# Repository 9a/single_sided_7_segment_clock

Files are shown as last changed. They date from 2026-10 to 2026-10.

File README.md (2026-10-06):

# Single Sided 7 segment clock PCB (optimized for use with ESP D1 Mini/ESP-home)
A pcb design for a 7 segment clock for single sided milled pcbs. Designed with KiCad 10. 

BOM (alternatives are also OK):
- 2x SN74HC595DR 
- 29x 150080RS75000
- 8x 10 Ohm 0805 (or 0603)

See schematic/placement picture for assembly (diode orientation!). The through holes other than for the 5 pin connector need to be connected via jumper wires.

It is designed to be connected to a USB-C ESP8266 D1-mini with a one to one connection via jumper wires to the pins 5V GND D4 D3 D2. Since the pins expose the control pins of the shift registers any microcontroller can be adapted.

For use with ESP home in Homeassistant:
The provided esp_yaml.txt can be copied when creating the device, the cnc_display.h needs to be copied into the esphome directory.

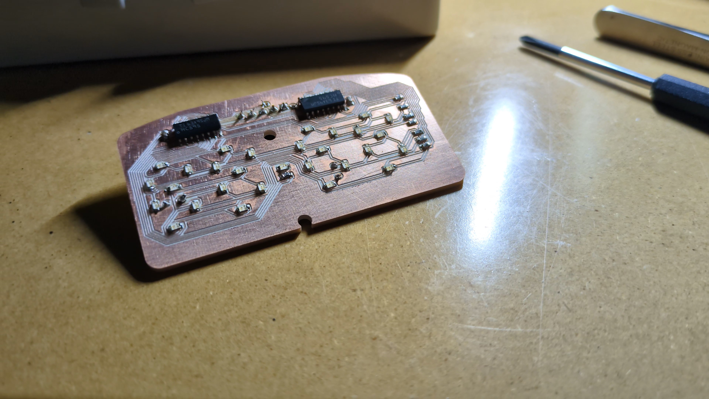
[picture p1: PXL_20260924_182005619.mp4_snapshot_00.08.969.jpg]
PCB


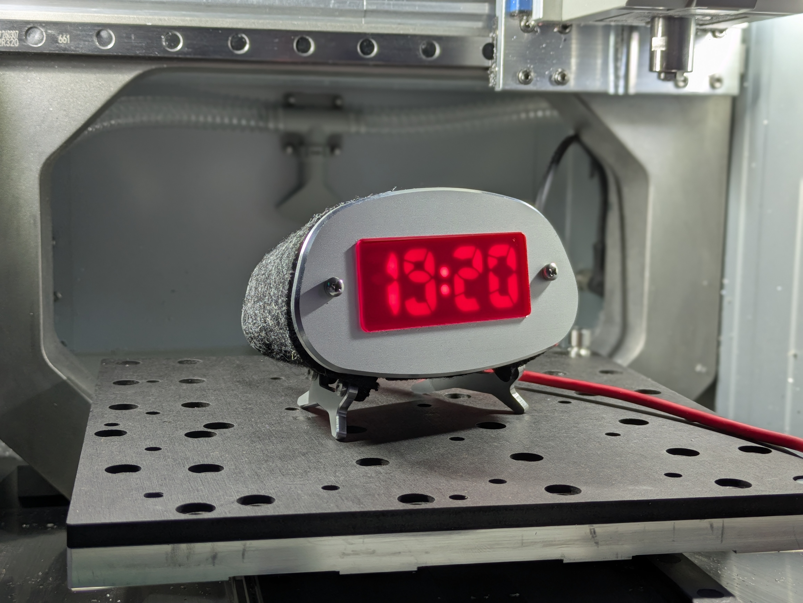
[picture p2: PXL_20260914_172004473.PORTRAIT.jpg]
finished_clock


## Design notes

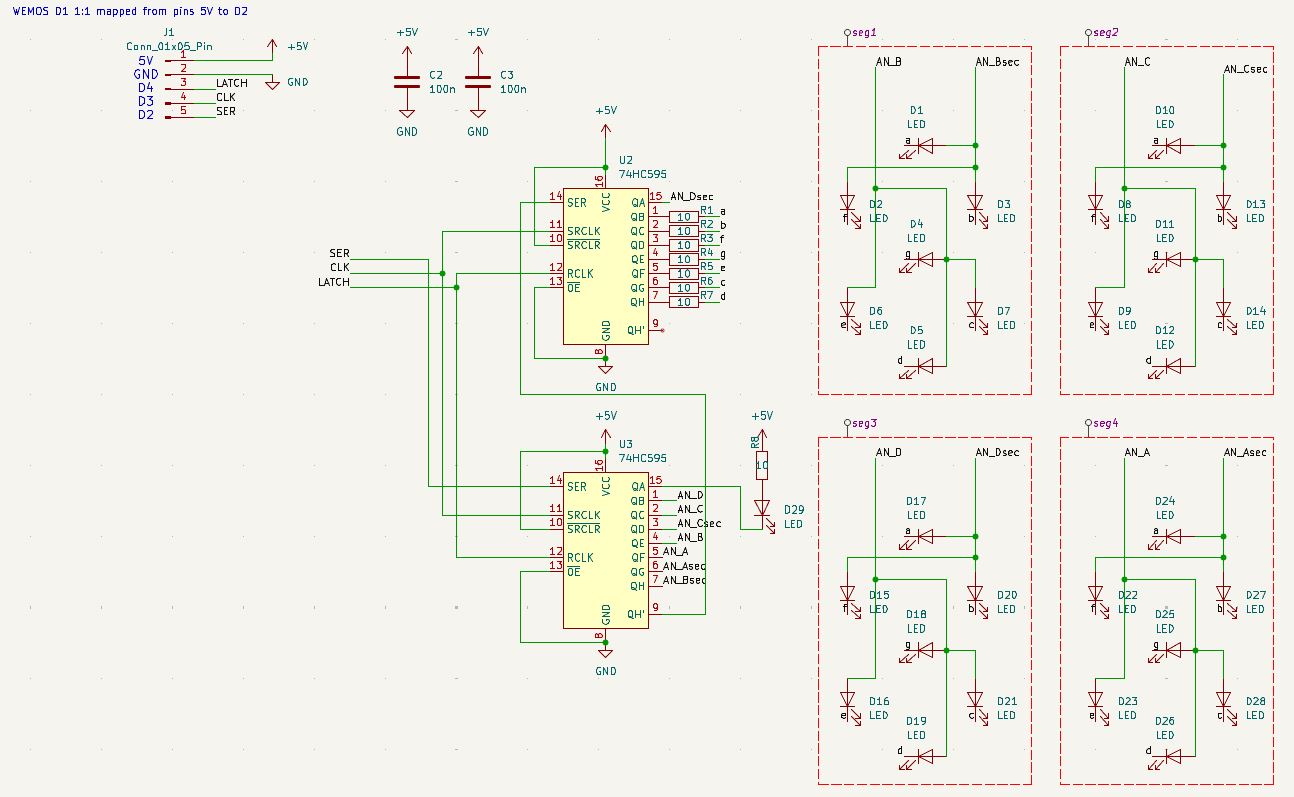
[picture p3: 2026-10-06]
esp_clock_schematic.JPG

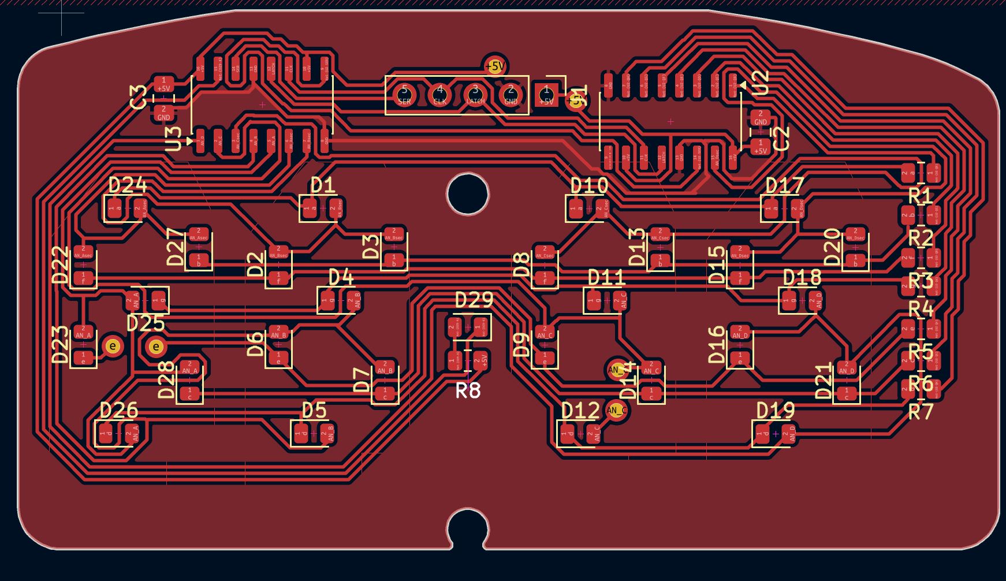
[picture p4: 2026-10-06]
placement.JPG

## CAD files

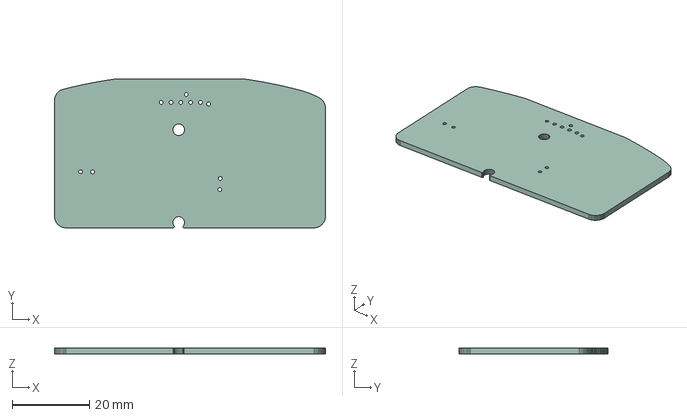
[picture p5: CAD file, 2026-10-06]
clock_pcb.step
70.1 x 38.5 x 1.51 mm

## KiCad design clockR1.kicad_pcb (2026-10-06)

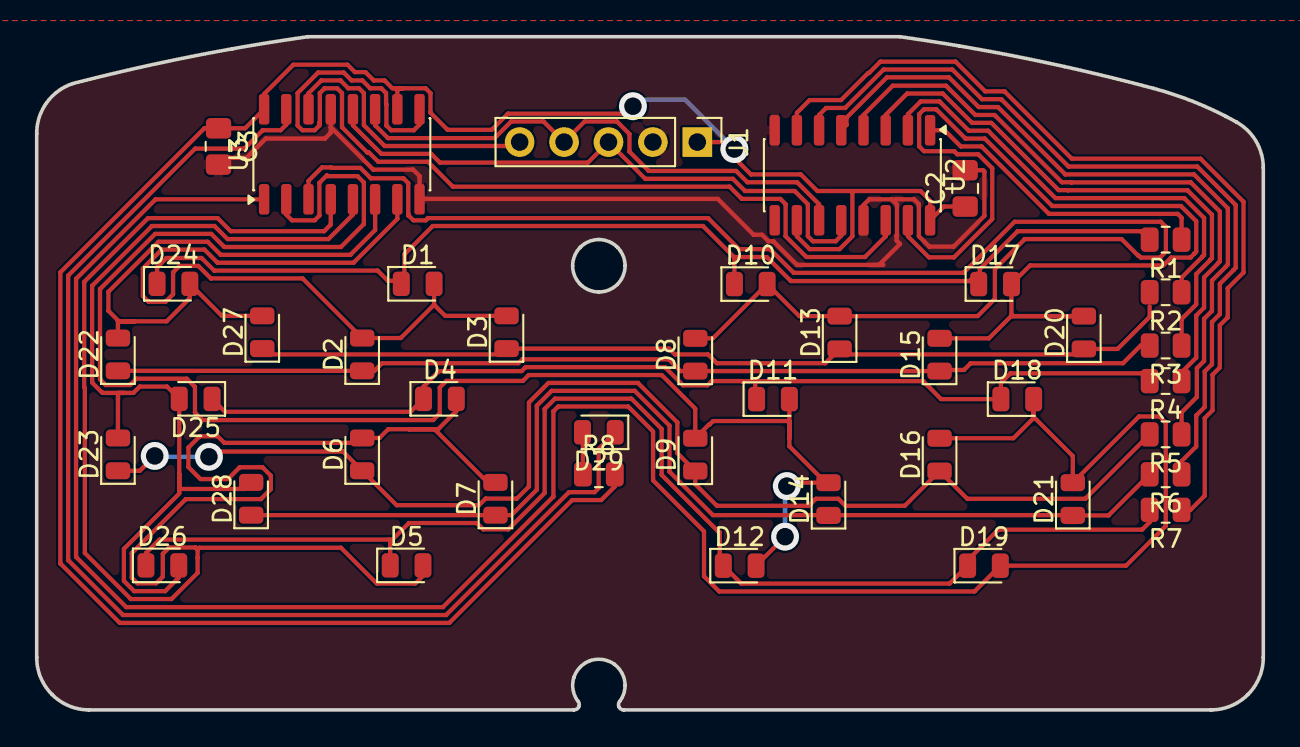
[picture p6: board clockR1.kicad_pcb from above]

Board: 2 copper layers, 70.1 x 38.5 mm, 42 parts (0 on the bottom side), 30 nets.

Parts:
C2, C3: C; C_0805_2012Metric_Pad1.18x1.45mm_HandSolder
D1, D2, D3, D4, D5, D6, D7, D8, D9, D10, D11, D12, D13, D14, D15, D16, D17, D18, D19, D20, D21, D22, D23, D24, D25, D26, D27, D28, D29: LED; LED_0805_2012Metric
J1: Conn_01x05_Pin; PinHeader_1x05_P2.54mm_Vertical
R1, R2, R3, R4, R5, R6, R7, R8: 100; R_0805_2012Metric
U2, U3: 74HC595; SO-16_3.9x9.9mm_P1.27mm

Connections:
+5V: C2.1, C3.1, J1.1, R8.2, U2.10 (~SRCLR), U2.16 (VCC), U3.10 (~SRCLR), U3.16 (VCC)
/AN_A: D23.2 (A), D25.2 (A), D26.2 (A), D28.2 (A), U3.5 (QF)
/AN_Asec: D22.2 (A), D24.2 (A), D27.2 (A), U3.6 (QG)
/AN_B: D4.2 (A), D5.2 (A), D6.2 (A), D7.2 (A), U3.4 (QE)
/AN_Bsec: D1.2 (A), D2.2 (A), D3.2 (A), U3.7 (QH)
/AN_C: D9.2 (A), D11.2 (A), D12.2 (A), D14.2 (A), U3.2 (QC)
/AN_Csec: D8.2 (A), D10.2 (A), D13.2 (A), U3.3 (QD)
/AN_D: D16.2 (A), D18.2 (A), D19.2 (A), D21.2 (A), U3.1 (QB)
/AN_Dsec: D15.2 (A), D17.2 (A), D20.2 (A), U2.15 (QA)
/CLK: J1.4, U2.11 (SRCLK), U3.11 (SRCLK)
/LATCH: J1.3, U2.12 (RCLK), U3.12 (RCLK)
/SER: J1.5, U3.14 (SER)
/a: D1.1 (K), D10.1 (K), D17.1 (K), D24.1 (K), R1.2
/b: D3.1 (K), D13.1 (K), D20.1 (K), D27.1 (K), R2.2
/c: D7.1 (K), D14.1 (K), D21.1 (K), D28.1 (K), R6.2
/d: D5.1 (K), D12.1 (K), D19.1 (K), D26.1 (K), R7.2
/e: D6.1 (K), D9.1 (K), D16.1 (K), D23.1 (K), R5.2
/f: D2.1 (K), D8.1 (K), D15.1 (K), D22.1 (K), R3.2
/g: D4.1 (K), D11.1 (K), D18.1 (K), D25.1 (K), R4.2
GND: C2.2, C3.2, J1.2, U2.8 (GND), U2.13 (~OE), U3.8 (GND), U3.13 (~OE)
unnamed: D29.2 (A), R8.1
unnamed: D29.1 (K), U3.15 (QA)
unnamed: R1.1, U2.1 (QB)
unnamed: R2.1, U2.2 (QC)
unnamed: R3.1, U2.3 (QD)
unnamed: R4.1, U2.4 (QE)
unnamed: R5.1, U2.5 (QF)
unnamed: R6.1, U2.6 (QG)
unnamed: R7.1, U2.7 (QH)
unnamed: U2.14 (SER), U3.9 (QH')

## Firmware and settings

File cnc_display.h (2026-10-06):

/*
*  This program originally was programmed for Arduino and
*  was vibe-ported to ESP home via ChatGPT.
*
*  All digits have common segment lines and are multiplexed
*  Pin assignment was optimized for single sided PCB routing
*  Check the KiCad dchematic for details.
*/

#pragma once

#include <Arduino.h>
#include <stdint.h>

// ============================================================
// ORIGINAL WIRING
//
// D4 / GPIO2 = LATCH
// D3 / GPIO0 = CLOCK
// D2 / GPIO4 = DATA
//
// No hardware SPI.
// ============================================================

#define CNC_LATCH  2
#define CNC_CLOCK  0
#define CNC_DATA   4


// ============================================================
// DISPLAY TIMING
//
// 1000 us per digit (4ms for all of the display)
//
// ============================================================

#define CNC_DIGIT_PERIOD_US 1000


// ============================================================
// ESP8266 timer1
//
// TIM_DIV16:
//
// 80 MHz / 16 = 5 MHz
//
// 1 timer tick = 200 ns
//
// ============================================================

#define CNC_TIMER_TICKS_PER_US 5


// ============================================================
// Blanking time
//
// Small OFF period around the data transfer prevents ghosting.
//
// ============================================================

#define CNC_BLANK_US 2


// ============================================================
// Segment mapping
//
// see KiCad file for pinmapping 
// ============================================================

static uint8_t cnc_segment[10] = {
    0b0001000,  // 0
    0b1011101,  // 1
    0b0010010,  // 2
    0b0010100,  // 3
    0b1000101,  // 4
    0b0100100,  // 5
    0b0100000,  // 6
    0b0011101,  // 7
    0b0000000,  // 8
    0b0000100   // 9
};


// ============================================================
// Digit selection mapping
//
// since 4 outputs of the shift registers were available
// LED anode switching was split in two separate "supplies"
// increasing the output current and thus the brightness of
// the segments
// ============================================================

static uint8_t cnc_bitmask[4] = {
    0b00000110,  // digit 0
    0b00001001,  // digit 1
    0b00110000,  // digit 2
    0b01000000   // digit 3
};


// ============================================================
// Display state
// ============================================================

volatile uint8_t cnc_digits[4] = {
    8, 8, 8, 8
};

volatile uint8_t cnc_colon = 0;

volatile uint8_t cnc_brightness = 100;

volatile uint8_t cnc_current_digit = 0;


// ============================================================
// Direct GPIO
//
// ESP8266:
//
// GPIO 0..15 are controlled through GPOS/GPOC.
//
// GPOS = set HIGH
// GPOC = set LOW
// ============================================================

IRAM_ATTR static inline void cnc_latch_low()
{
    GPOC = (1U << CNC_LATCH);
}

IRAM_ATTR static inline void cnc_latch_high()
{
    GPOS = (1U << CNC_LATCH);
}

IRAM_ATTR static inline void cnc_clock_low()
{
    GPOC = (1U << CNC_CLOCK);
}

IRAM_ATTR static inline void cnc_clock_high()
{
    GPOS = (1U << CNC_CLOCK);
}

IRAM_ATTR static inline void cnc_data_low()
{
    GPOC = (1U << CNC_DATA);
}

IRAM_ATTR static inline void cnc_data_high()
{
    GPOS = (1U << CNC_DATA);
}


// ============================================================
// Software SPI
//
// Equivalent to:
//
// shiftOut(DATA, CLOCK, LSBFIRST, value);
//
// but considerably faster because it avoids digitalWrite().
// ============================================================

IRAM_ATTR static inline void cnc_shift_byte(
    uint8_t value
)
{
    for (uint8_t i = 0; i < 8; i++) {

        if (value & 1) {
            cnc_data_high();
        } else {
            cnc_data_low();
        }

        cnc_clock_high();
        cnc_clock_low();

        value >>= 1;
    }
}


// ============================================================
// Blank the display
//
// We send both registers zero.
//
// This ensures there is no visible digit while we load the
// next 16 bits.
// ============================================================

IRAM_ATTR static inline void cnc_blank()
{
    cnc_latch_low();

    cnc_shift_byte(0);
    cnc_shift_byte(0);

    cnc_latch_high();
}


// ============================================================
// Load one digit
//
// Same byte order and bit order as your original code.
//
// ============================================================

IRAM_ATTR static inline void cnc_load_digit(
    uint8_t digit
)
{
 
	uint8_t bitm = 0;
	uint8_t first = 0;
	uint8_t second = (1 << 7);

    // Colon on digit 3.
    if (digit == 3) {
        bitm = 1;
    }
	
	if (digit < 4) {
		first =
			(bitm << 7) |
			cnc_segment[cnc_digits[digit]];
			
			
		if (cnc_colon) {
			bitm = 0;
		}

		second =
			cnc_bitmask[digit] |
			((1 ^ bitm) << 7);		
	}


    cnc_latch_low();

    cnc_shift_byte(first);
    cnc_shift_byte(second);

    cnc_latch_high();
}


// ============================================================
// Timer ISR
//
// We use two phases:
//
// PHASE 0:
//     blank
//     load next digit
//     turn digit on
//
// PHASE 1:
//     blank digit
//
// This gives PWM brightness without changing the multiplex
// frequency.
//
// only digit 0, 1, 2 and 3 cause segments to light up, so 
// having cnc_current_digit can be variably large to controll
// brightness
//
// ============================================================

volatile bool cnc_digit_on = false;

IRAM_ATTR void cnc_display_timer()
{
    //cnc_blank();

    cnc_load_digit(cnc_current_digit);

    cnc_current_digit++;

    if (cnc_current_digit >= (4 + (20 - cnc_brightness/5))) {
        cnc_current_digit = 0;
    }

    timer1_write(
        CNC_TIMER_TICKS_PER_US *
        CNC_DIGIT_PERIOD_US
    );
}


// ============================================================
// Start timer
// ============================================================

void cnc_display_setup()
{
    pinMode(CNC_LATCH, OUTPUT);
    pinMode(CNC_CLOCK, OUTPUT);
    pinMode(CNC_DATA, OUTPUT);

    digitalWrite(CNC_LATCH, HIGH);
    digitalWrite(CNC_CLOCK, LOW);
    digitalWrite(CNC_DATA, LOW);

    cnc_current_digit = 0;

    timer1_isr_init();

    timer1_attachInterrupt(cnc_display_timer);

    timer1_enable(
        TIM_DIV16,
        TIM_EDGE,
        TIM_LOOP
    );

    timer1_write(
        CNC_TIMER_TICKS_PER_US *
        CNC_DIGIT_PERIOD_US
    );
}

// ============================================================
// Update display data from normal ESPHome code
// ============================================================

void cnc_display_set_digits(
    uint8_t d0,
    uint8_t d1,
    uint8_t d2,
    uint8_t d3,
    bool colon
)
{
    noInterrupts();

    cnc_digits[0] = d0;
    cnc_digits[1] = d1;
    cnc_digits[2] = d2;
    cnc_digits[3] = d3;

    cnc_colon = colon ? 1 : 0;

    interrupts();
}
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
